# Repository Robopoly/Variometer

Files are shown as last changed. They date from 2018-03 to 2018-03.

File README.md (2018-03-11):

# Variometer
Un variometre programmé en arduino   
  
Le principe de celui est d'indiquer la vitesse verticale à son utilisateur, appareil très utilisé par les pilotes de planeurs ou parapentes pour trouver les courants ascendants.    
Le variometre produits des bips en fonctions de la vitesse, plus celle-ci est élévée plus les bips sont rapprochés et aigus.  
Des bips plus graves indiquent que l'on se trouve dans un courant descendant.  
Le variometre dispose également d'un mode vibreur activable via un bouton : le moteur vibrant s'active lorsqu'on monte

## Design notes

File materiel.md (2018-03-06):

Buzzer  
Resistance 1k Ohm  
Resistance 150 Ohm  
Capacité 1 uF  
Diode 1n4001 
Moteur vibrant  
Baromètre BMP280  
Switch  
Bouton  
Trinket pro 3V d'adafruit  
Lipo backpack d'adafruit  
Lipo 1s

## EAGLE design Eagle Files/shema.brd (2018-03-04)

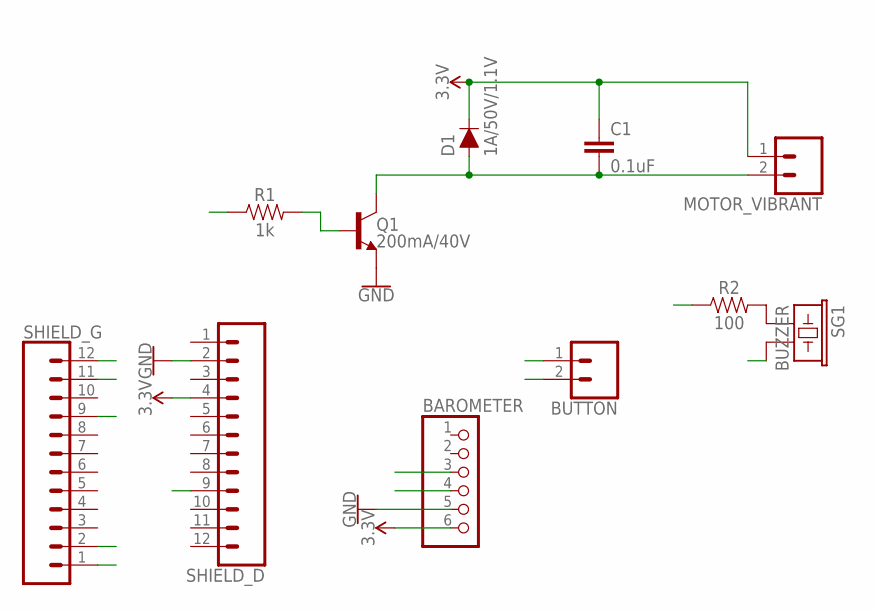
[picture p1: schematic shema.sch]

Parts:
BAROMETER: PINHD-1X6; 1X06
BUTTON: CONN_02; 1X02
C1: 0.1uF; CAP-PTH-SMALL-KIT
D1: 1A/50V/1.1V; DIODE-1N4001
MOTOR_VIBRANT: CONN_02; 1X02
Q1: 200mA/40V; TO-92
R1: 1k; AXIAL-0.3
R2: 100; AXIAL-0.3EZ
SG1: BUZZER; PS1240P02BT
SHIELD_D: CONN_12; 1X12
SHIELD_G: CONN_12; 1X12

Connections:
AUDIO0: SG1.P$2 (2), SHIELD_G.12
AUDIO1: R2.P$1 (1), SHIELD_G.11
BUTTON: BUTTON.2, SHIELD_D.9
GND: BAROMETER.5, BUTTON.1, Q1.1 (E), SHIELD_D.2
MOTOR_CONTROL: R1.P$1 (1), SHIELD_G.9
unnamed: C1.2, D1.A, MOTOR_VIBRANT.2, Q1.3 (C)
unnamed: R2.P$2 (2), SG1.P$1 (1)
SCL: BAROMETER.4, SHIELD_G.1
SDA: BAROMETER.3, SHIELD_G.2
VCC: BAROMETER.6, C1.1, D1.C, MOTOR_VIBRANT.1, SHIELD_D.4
ZBRA: Q1.2 (B), R1.P$2 (2)

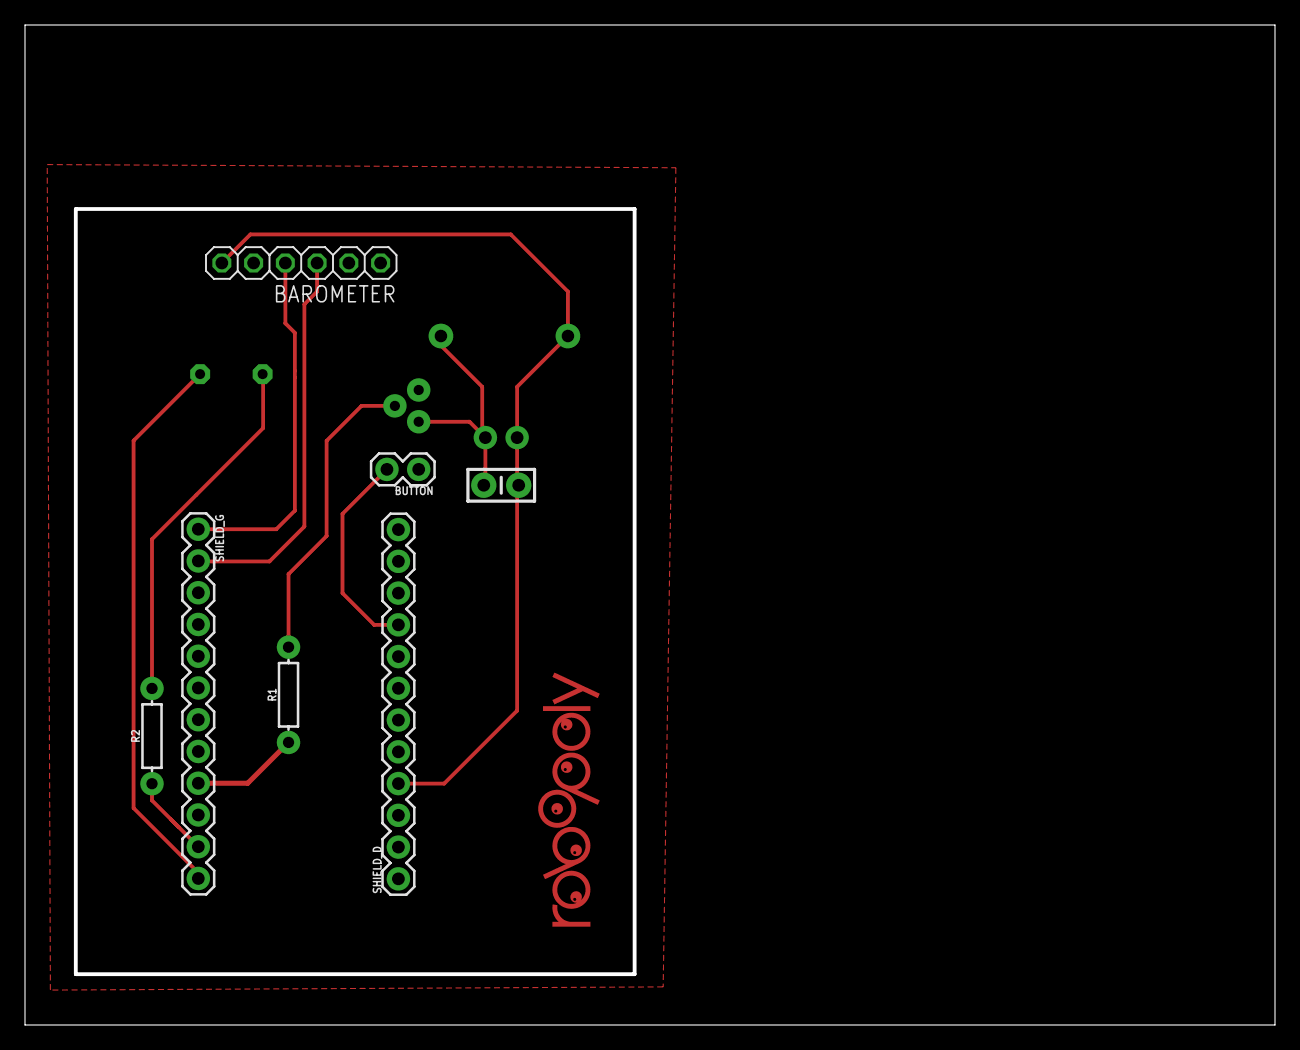
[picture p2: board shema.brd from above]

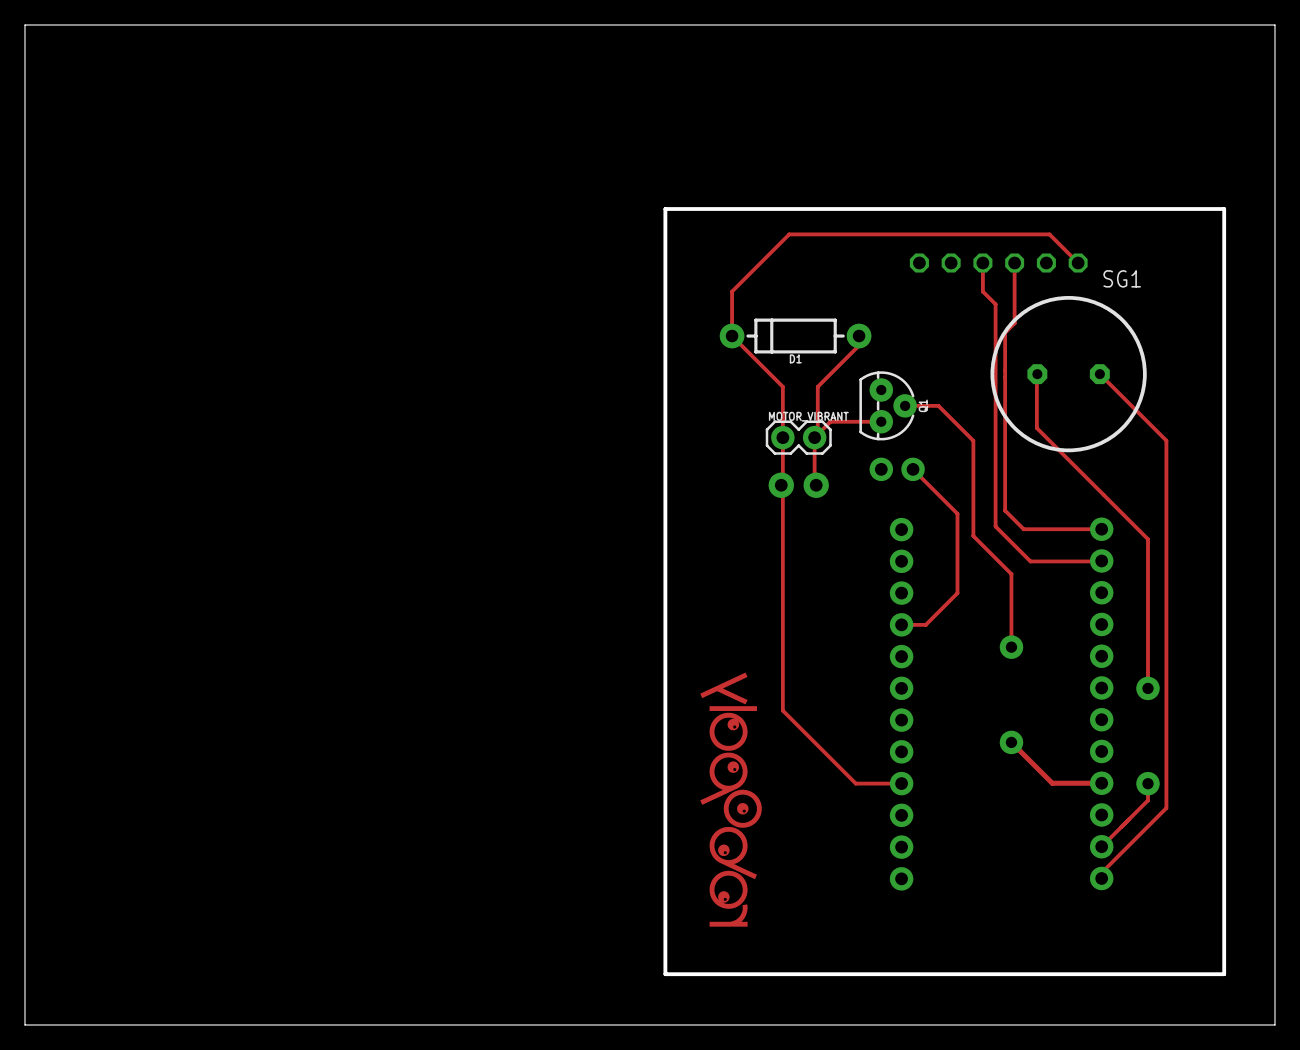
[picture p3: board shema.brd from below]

Board: 2 copper layers, 100.0 x 80.0 mm, 12 parts (4 on the bottom side), 11 nets.

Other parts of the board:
U$1: ROBOPOLY-LOGO-SYMBOL

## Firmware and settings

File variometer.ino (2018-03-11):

#include <Wire.h>
#include <SPI.h>
#include <toneAC.h> 
#include <Adafruit_Sensor.h>
#include <Adafruit_BMP280.h>

#define pressure_0 1015.25  // Pression QNH du jour
#define alt_max 1700    // Altitude maximal (permet de faire une alerte : dépassement de la TMA ...)

// Pins utilises, le buzzer sont sur les pins 9 & 10 pour l'atmega 328 (voir librairie toneAC)
#define vibrant 12
#define button 3

Adafruit_BMP280 bme;  // cree objet barometre

float alt = 1000, alt_old = 1000; // valeur initiale permettant de converger plus vite vers la vraie valeur
float t, t_old = millis();
float vario = 0;

// vitesses entre lequels le variometre ne fera pas de bips 
const float vario_climb_start = 0; 
const float vario_sink_start = -1.3; 

// variables pour le bouton
bool state = 0;         
bool buttonState;             
bool lastButtonState = LOW;   
unsigned long lastDebounceTime = 0;  
unsigned long debounceDelay = 50; 


float timer = millis();
uint8_t beepLatency;
uint16_t beepFrequency;


void updateAlt(){
  alt = alt * 0.99 + 0.01 * bme.readAltitude(pressure_0);
}

void updateVario(){
  vario = vario * 0.99 + 10000 * ((alt-alt_old)/(t-t_old));
}


void vibrate(){
  if (vario > vario_climb_start)
    digitalWrite(vibrant, 1);
  else
    digitalWrite(vibrant, 0);
}


void button_check(){

  bool reading = digitalRead(button);
  
  if (reading != lastButtonState) {
    lastDebounceTime = millis();
  }

  if ((millis() - lastDebounceTime) > debounceDelay) {

    if (reading != buttonState) {
      buttonState = reading;

      if (buttonState == HIGH) {
        state = !state;
      }
    }
  }
  lastButtonState = reading;
}


uint16_t getBeepFrequency(float vario)
{
  int frequency = 690 + (120 * vario);
  return (frequency < 200) ? 200 : (frequency > 1300) ? 1300 : frequency;
}

uint8_t getBeepLatency(float vario)
{
  int latency = 200 - (vario * 26);
  return (latency < 70) ? 70 : (latency > 200) ? 200 : latency;
}


void makeBeeps(){
    digitalWrite(vibrant, 0);
    if (vario >= vario_climb_start || vario <= vario_sink_start){
      beepLatency = getBeepLatency(vario);
      beepFrequency = getBeepFrequency(vario);
    
      if ( millis()>= timer  + beepLatency*4){
        toneAC (beepFrequency, 10, beepLatency/2);
        timer = millis();    
    }
  }
}


void setup() {

  pinMode(vibrant, OUTPUT);
  pinMode(button, INPUT_PULLUP);
  
 if (!bme.begin()){ // initialisation du baromètre 
  while (1){
    digitalWrite(LED_BUILTIN, HIGH);   
    delay(1000);                      
    digitalWrite(LED_BUILTIN, LOW);    
    delay(1000);   
  }
 }
}



void loop() {
  t = micros();
  updateAlt();
  button_check();
  updateVario();
  
  if(alt > alt_max)
    toneAC(3000);
  else{
    if (state)
      makeBeeps();
    else
      vibrate();
  }
  alt_old = alt;
  t_old = t; 
  

}

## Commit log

2018-03-06 jkj
    lkjlkj
    [shema.brd, shema.sch]
2018-03-11 Eagle Files
    Eagle Files
    [shema.brd, shema.sch]

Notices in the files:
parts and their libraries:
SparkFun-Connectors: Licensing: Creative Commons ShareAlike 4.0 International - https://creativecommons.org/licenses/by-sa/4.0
